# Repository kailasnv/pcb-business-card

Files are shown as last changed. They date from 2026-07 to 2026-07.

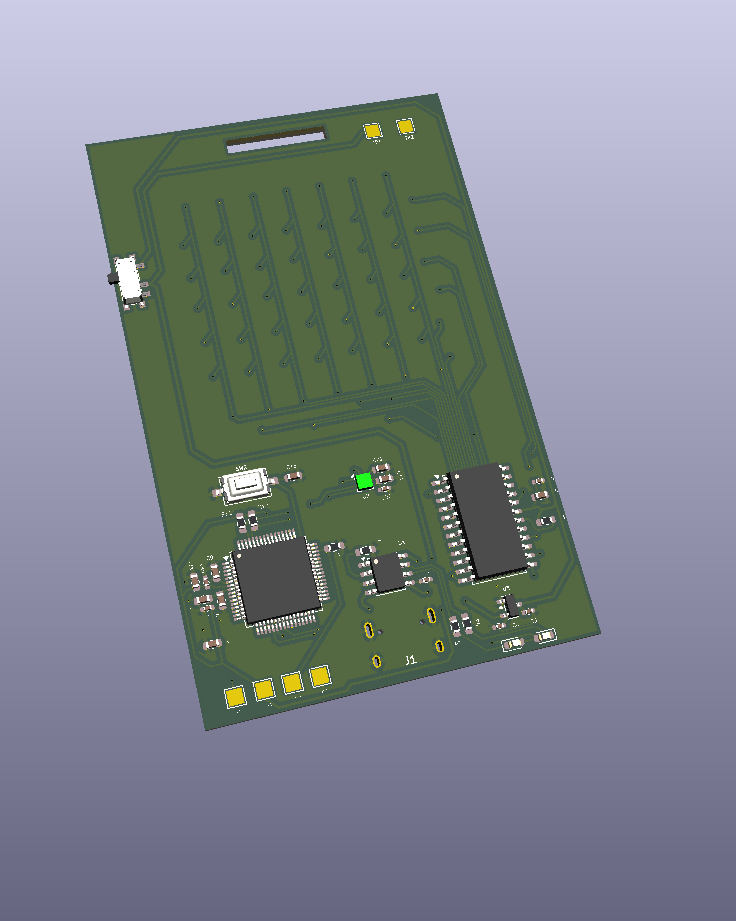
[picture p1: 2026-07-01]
docs/images/contact_card_v1.png

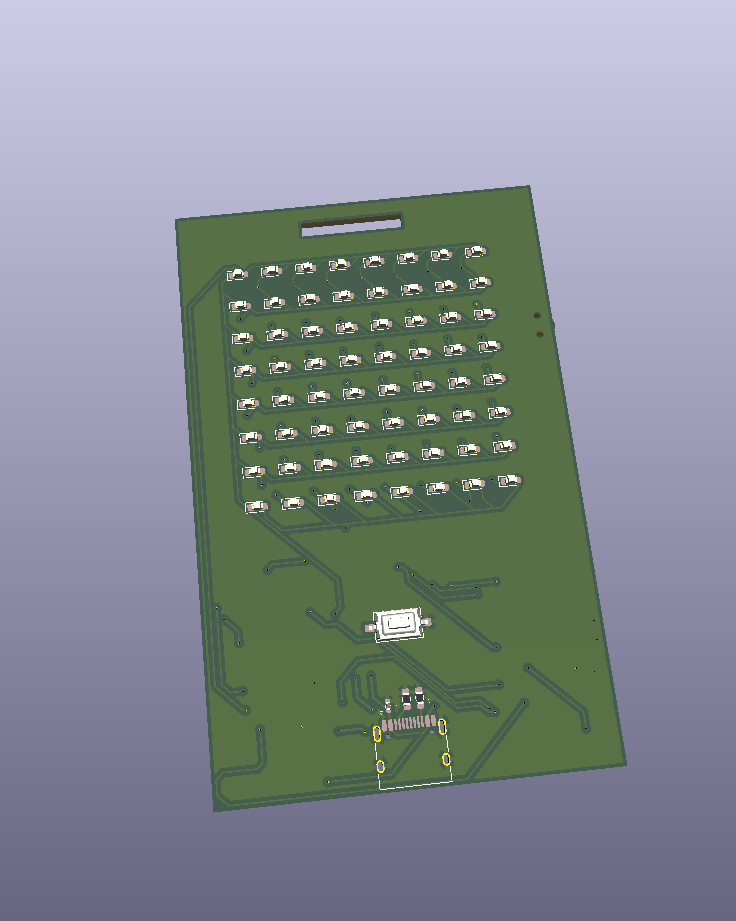
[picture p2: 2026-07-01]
docs/images/contact_card_v1_frontside.png

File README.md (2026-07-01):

# PCB Business Card

A creditcard sized custom PCB that doubles as a contact card and an interactive embedded demo. Designed from scratch, No dev board, no modules, bare chip bring up on a custom 2 layer board.

---

## What it does

| Mode | Trigger | Description |
|---|---|---|
| **Scroll** | Idle | Scrolls name and contact details across the 8×8 LED matrix |
| **Flappy Bird** | Button press | Classic Flappy Bird on an 8×8 grid |
| **Ball** | Tilt card | 1-pixel ball rolls around the matrix responding to physical tilt |

---

## Hardware

| Component | Part | Purpose |
|---|---|---|
| MCU | STM32G071RBT6 (LQFP-64) | Main processor, Cortex-M0+ @ 64MHz |
| LED Driver | MAX7219 (SOIC-24) | Drives 8×8 LED matrix over SPI |
| Display | 8×8 red LED matrix (0603 LEDs) | Output display |
| Accelerometer | IIS2DLPC (LGA-12) | 3-axis tilt sensing over I²C |
| Charger | TP4056 (SOP-8) | LiPo charging via USB-C |
| Regulator | MCP1700 | 3.3V LDO from LiPo |
| Power | 3.7V 1500mAh LiPo | Battery |
| Input | SMD tactile switch (3×6mm) | Game button |
| Connector | USB-C (16-pin SMD) | Charging input |

---

## Schematic overview

Five sub-circuits:
- **Power** — USB-C → TP4056 → LiPo → MCP1700 → 3.3V rail
- **MCU** — STM32G071RB with decoupling, BOOT0 pull-down, SWD pads
- **LED matrix** — MAX7219 driven over SPI, 64× 0603 LEDs in 8×8 grid
- **Accelerometer** — IIS2DLPC over I²C with additional INT1 interrupt line to MCU
- **Input** — Tactile button + 4-pad SWD debug port

---

###### Firmware (in progress)

---

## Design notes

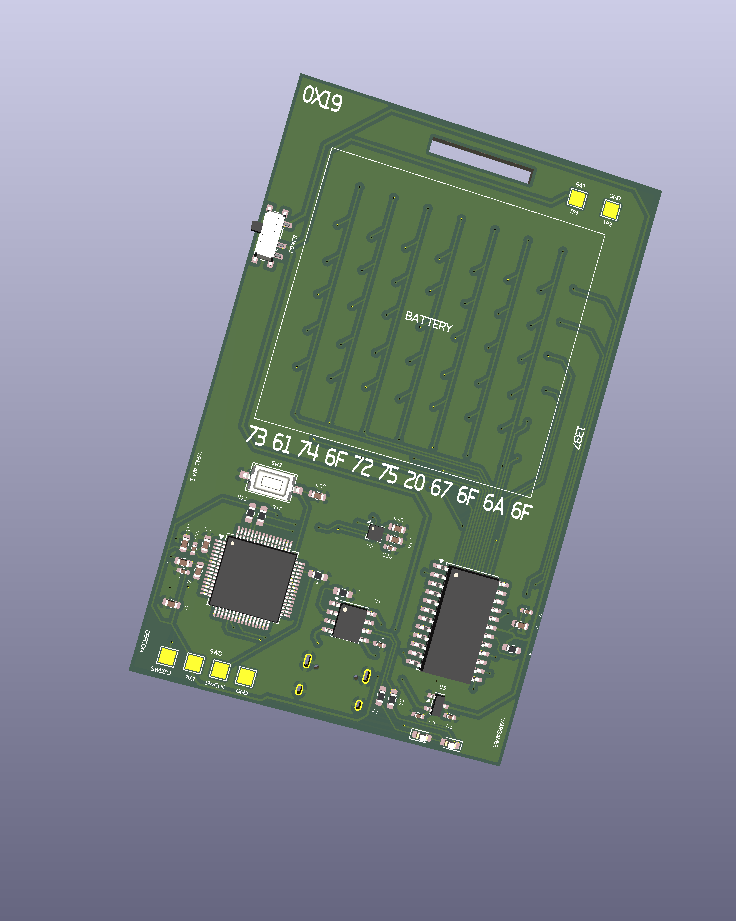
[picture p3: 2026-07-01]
docs/images/contact_card_v1_IMG3.png

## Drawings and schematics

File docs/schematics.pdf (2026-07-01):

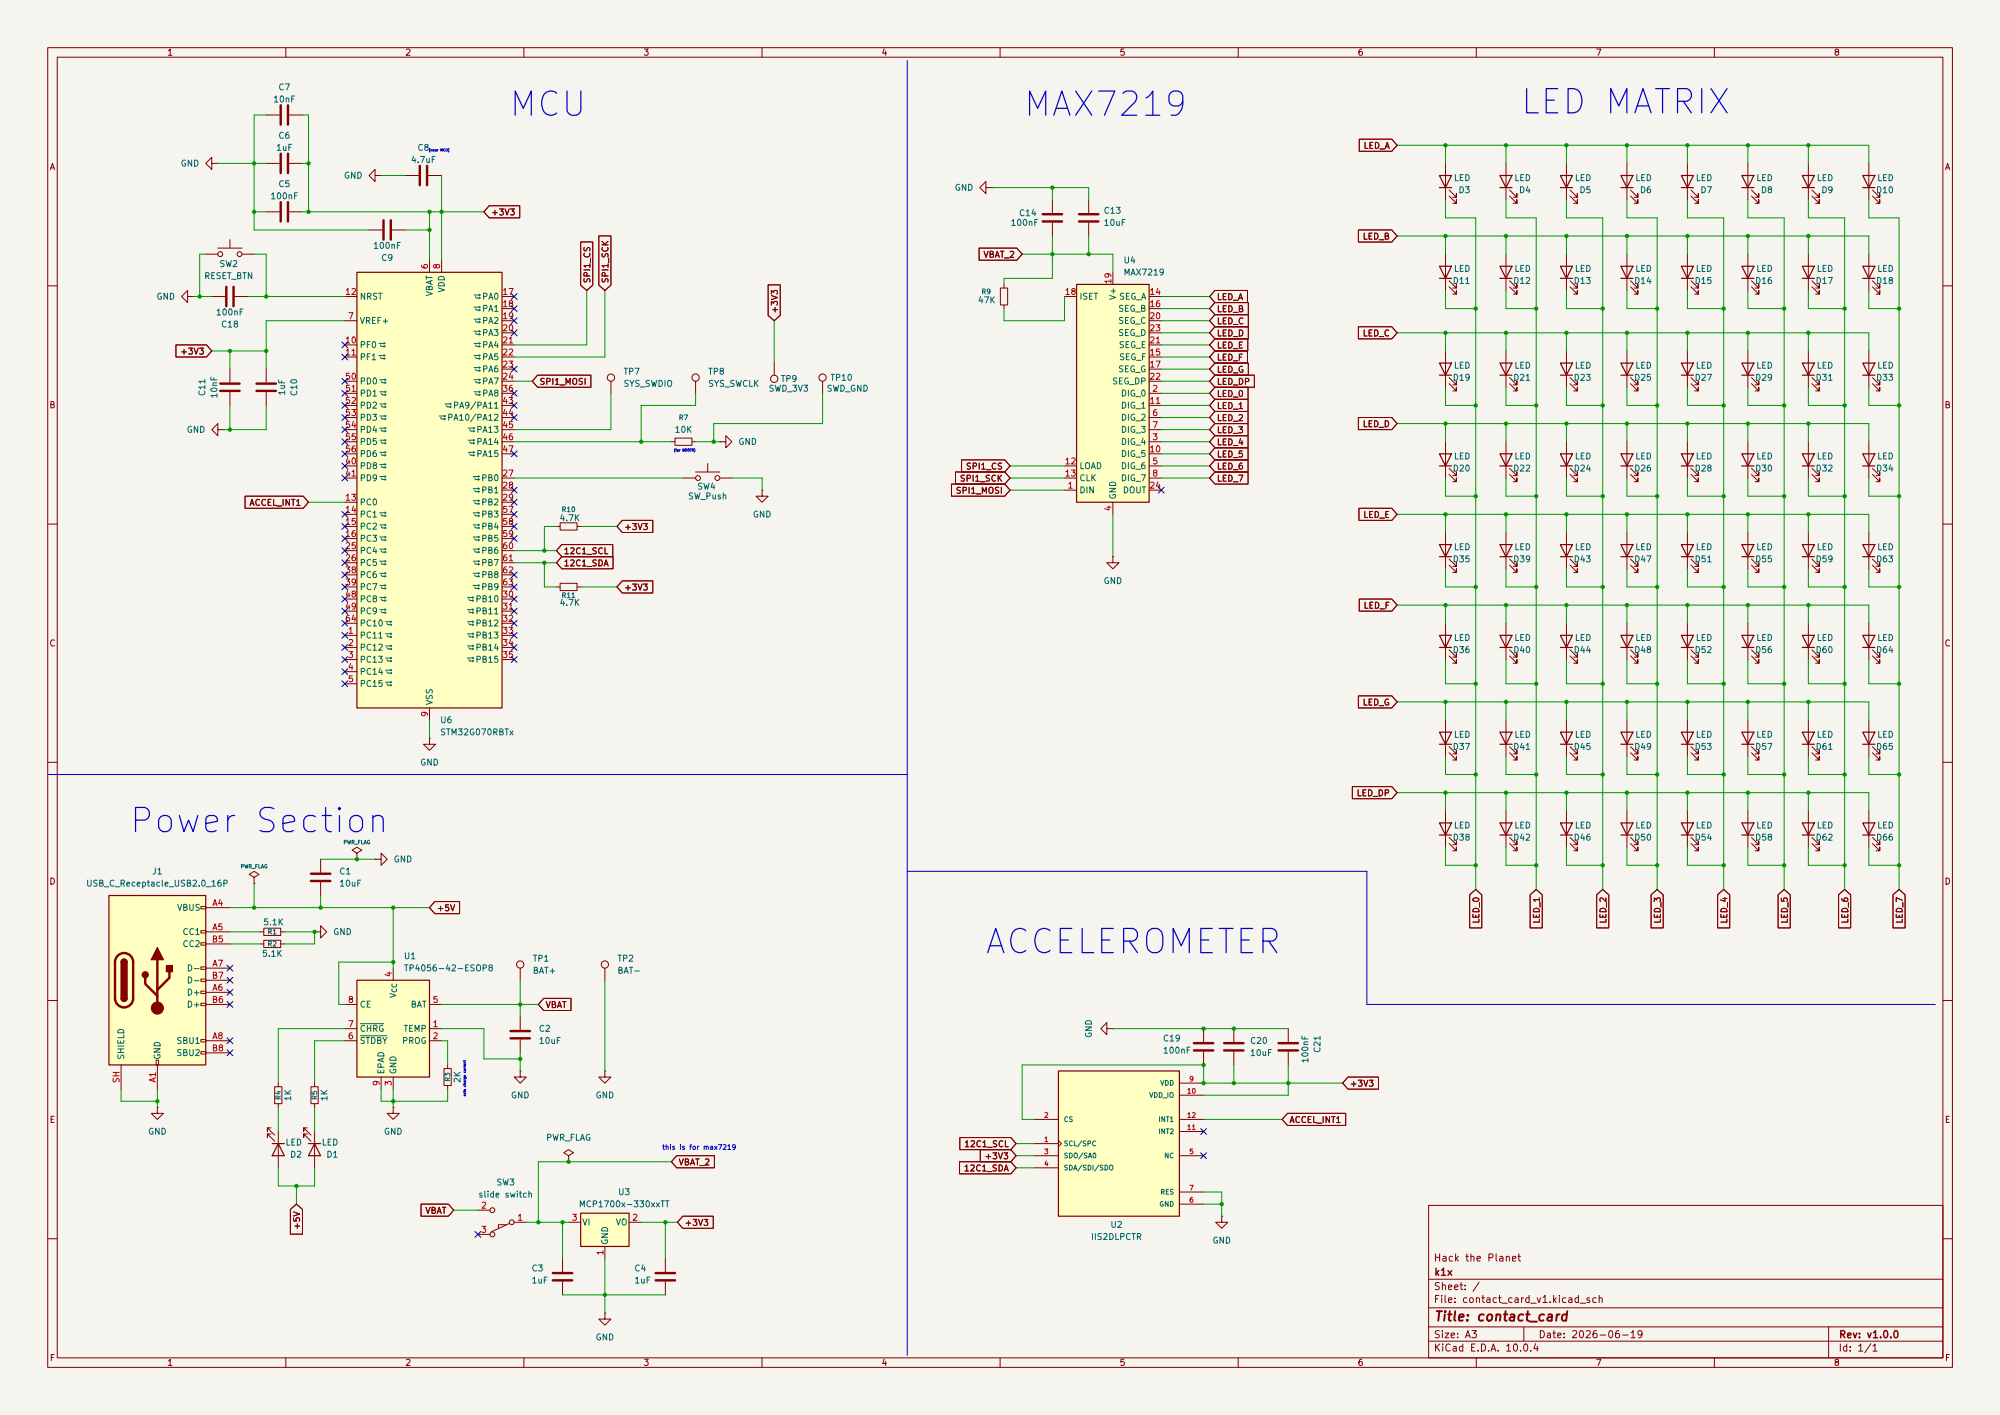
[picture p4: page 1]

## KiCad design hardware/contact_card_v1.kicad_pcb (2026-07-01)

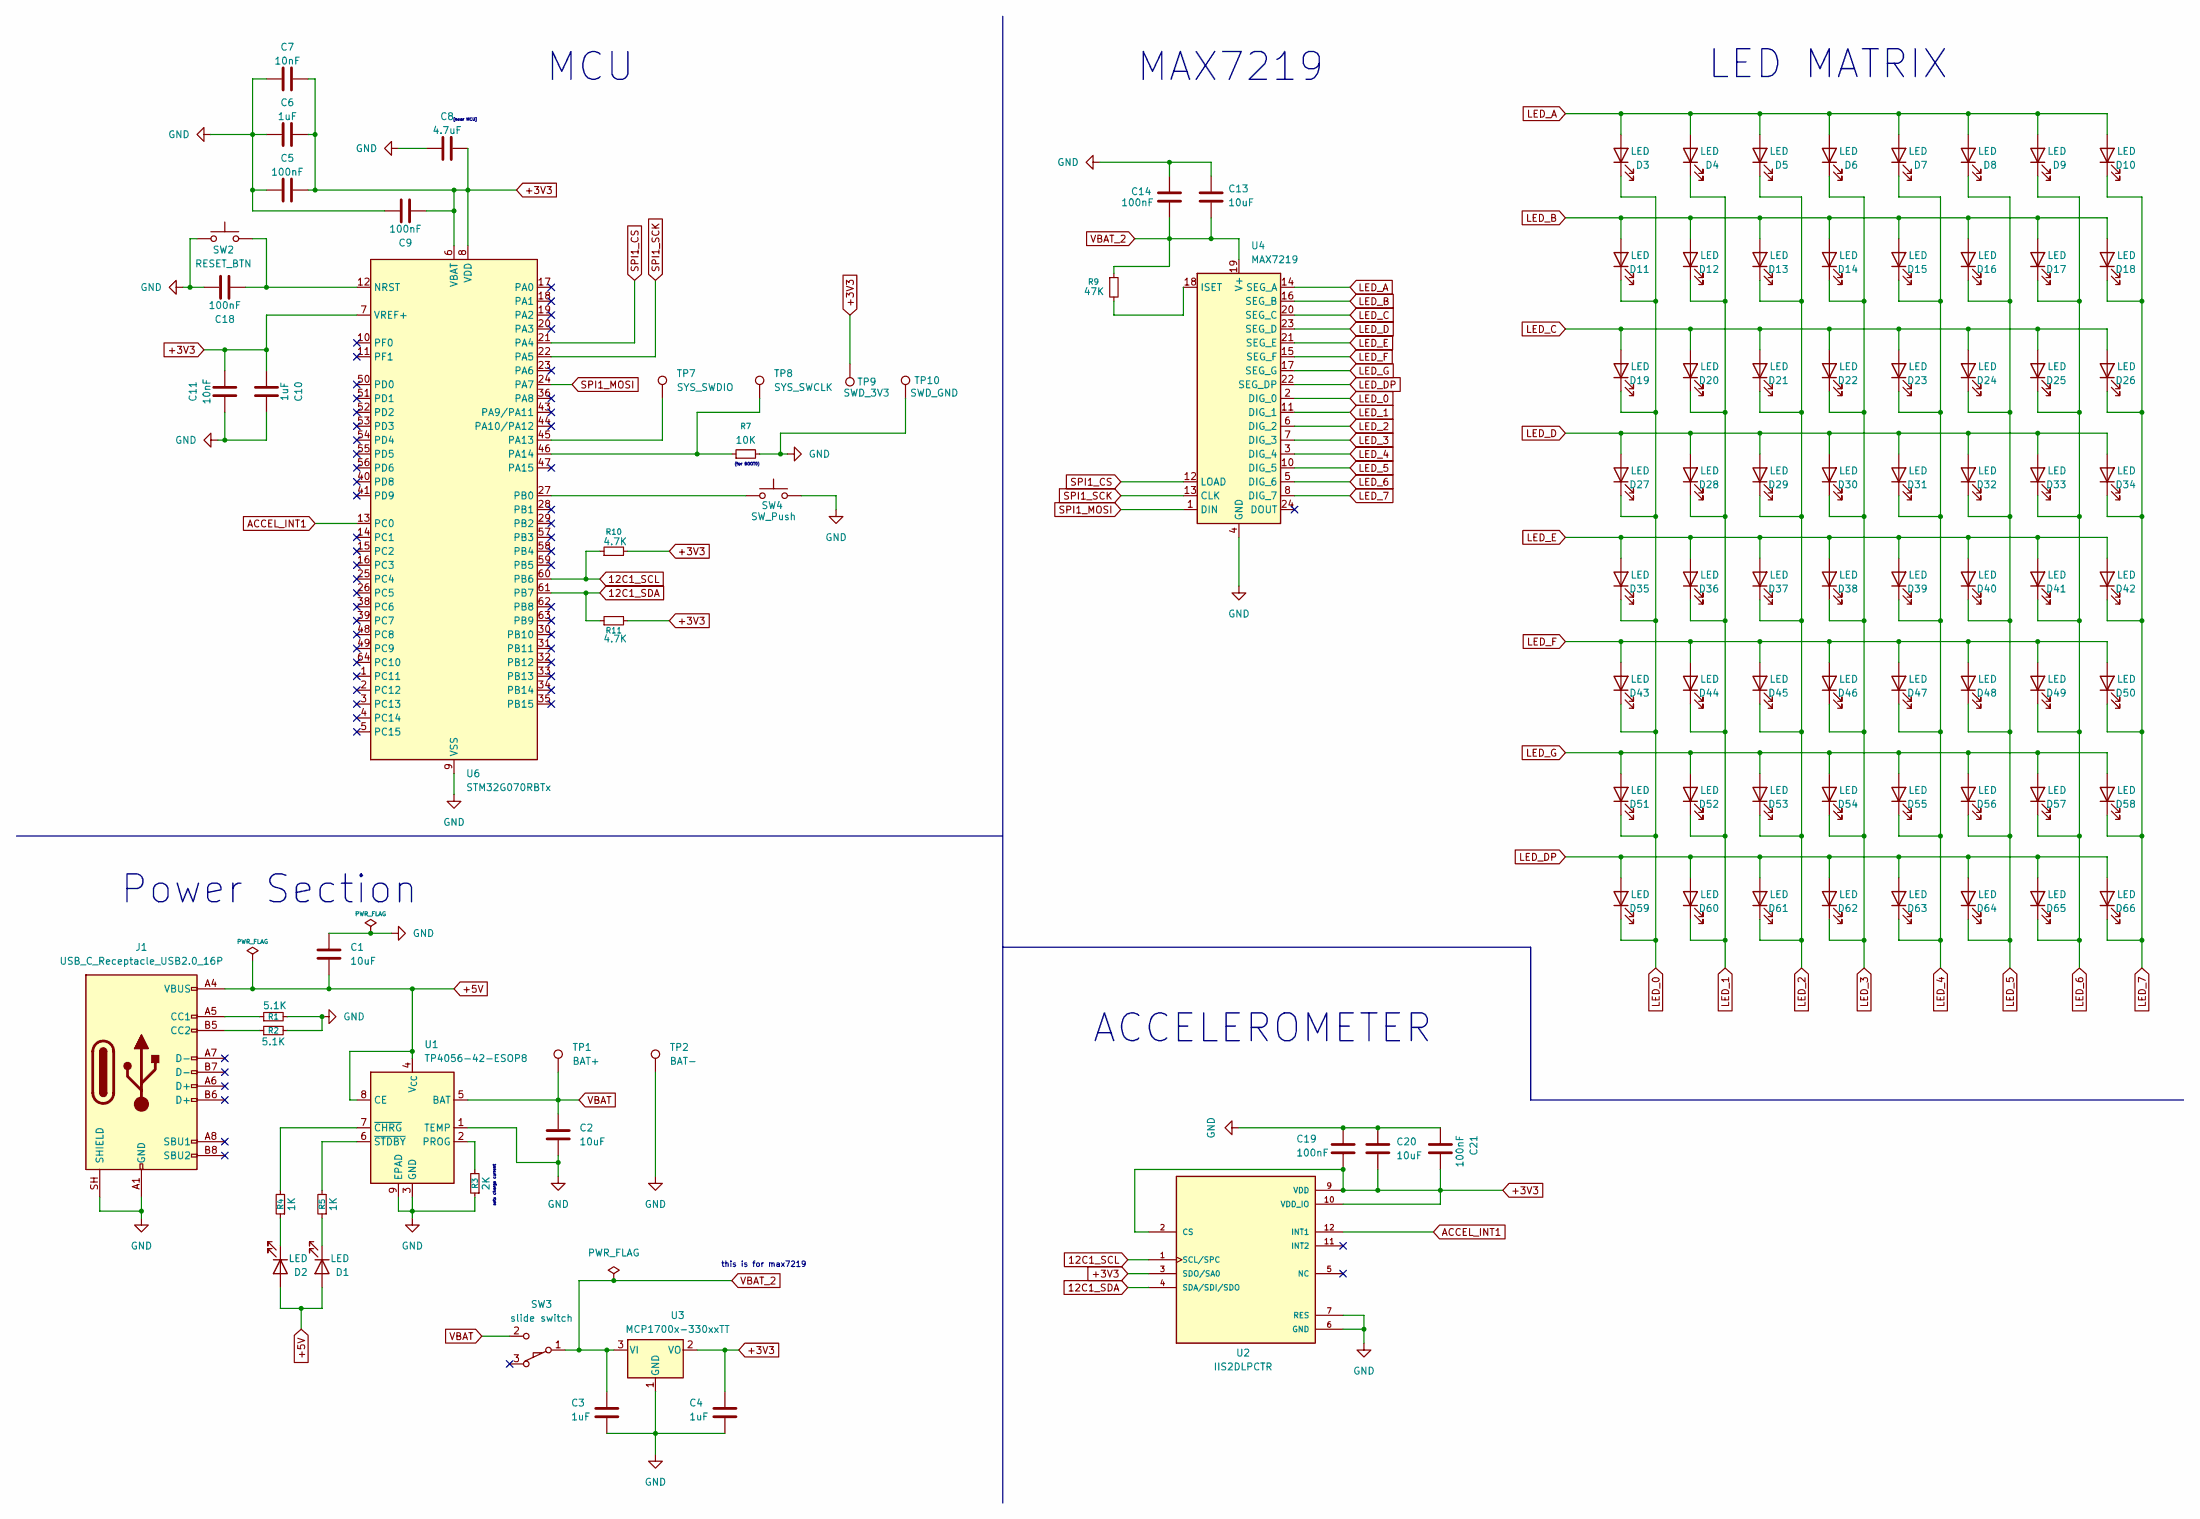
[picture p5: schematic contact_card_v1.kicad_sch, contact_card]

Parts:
C1, C2, C13, C20: 10uF; C_0402_1005Metric_Pad0.74x0.62mm_HandSolder
C3, C4, C6, C10: 1uF; C_0402_1005Metric_Pad0.74x0.62mm_HandSolder
C5, C9, C14, C18, C19, C21: 100nF; C_0603_1608Metric
C7, C11: 10nF; C_0603_1608Metric
C8: 4.7uF; C_0603_1608Metric
D1, D2, D3, D4, D5, D6, D7, D8, D9, D10, D11, D12, D13, D14, D15, D16, D17, D18, D19, D20, D21, D22, D23, D24, D25, D26, D27, D28, D29, D30, D31, D32, D33, D34, D35, D36, D37, D38, D39, D40, D41, D42, D43, D44, D45, D46, D47, D48, D49, D50, D51, D52, D53, D54, D55, D56, D57, D58, D59, D60, D61, D62, D63, D64, D65, D66: LED; LED_0603_1608Metric_Pad1.05x0.95mm_HandSolder
J1: USB_C_Receptacle_USB2.0_16P; USB_C_Receptacle_HRO_TYPE-C-31-M-12
R1, R2: 5.1K; R_0603_1608Metric_Pad0.98x0.95mm_HandSolder
R3: 2K; R_0603_1608Metric_Pad0.98x0.95mm_HandSolder
R4, R5: 1K; R_0603_1608Metric_Pad0.98x0.95mm_HandSolder
R7: 10K; R_0603_1608Metric_Pad0.98x0.95mm_HandSolder
R9: 47K; R_0603_1608Metric_Pad0.98x0.95mm_HandSolder
R10, R11: 4.7K; R_0603_1608Metric_Pad0.98x0.95mm_HandSolder
SW2: RESET_BTN; SW_Tactile_SPST_NO_Straight_CK_PTS636Sx25SMTRLFS
SW3: slide switch; SW_SPDT_PCM12
SW4: SW_Push; SW_Tactile_SPST_NO_Straight_CK_PTS636Sx25SMTRLFS
TP1: BAT+; TestPoint_Pad_2.0x2.0mm
TP2: BAT-; TestPoint_Pad_2.0x2.0mm
TP7: SYS_SWDIO; TestPoint_Pad_2.0x2.0mm
TP8: SYS_SWCLK; TestPoint_Pad_2.0x2.0mm
TP9: SWD_3V3; TestPoint_Pad_2.0x2.0mm
TP10: SWD_GND; TestPoint_Pad_2.0x2.0mm
U1: TP4056-42-ESOP8; SOIC-8-1EP_3.9x4.9mm_P1.27mm_EP2.29x3mm
U2: IIS2DLPCTR; LGA-12_2x2mm_P0.5mm; PARTREV 4
U3: MCP1700x-330xxTT; SOT-23
U4: MAX7219; SOIC-24W_7.5x15.4mm_P1.27mm
U6: STM32G070RBTx; LQFP-64_10x10mm_P0.5mm

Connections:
12C1_SCL: R10.1, U2.1 (SCL/SPC), U6.60 (PB6)
12C1_SDA: R11.1, U2.4 (SDA/SDI/SDO), U6.61 (PB7)
+3V3: C4.1, C5.2, C6.2, C7.2, C8.2, C9.1, C10.2, C11.1, C19.2, C20.2, C21.1, R10.2, R11.2, TP9.1 (1_1), U2.2 (CS), U2.3 (SDO/SA0), U2.9 (VDD), U2.10 (VDD_IO), U3.2 (VO), U6.6 (VBAT), U6.7 (VREF+), U6.8 (VDD)
+5V: C1.2, D1.2 (A), D2.2 (A), J1.A4 (VBUS), J1.A9 (VBUS), J1.B4 (VBUS), J1.B9 (VBUS), U1.4 (V_{CC}), U1.8 (CE)
ACCEL_INT1: U2.12 (INT1), U6.13 (PC0)
GND: C1.1, C2.2, C3.2, C4.2, C5.1, C6.1, C7.1, C8.1, C9.2, C10.1, C11.2, C13.1, C14.1, C18.2, C19.1, C20.1, C21.2, J1.A1 (GND), J1.A12 (GND), J1.B1 (GND), J1.B12 (GND), J1.SH (SHIELD), R1.2, R2.2, R3.1, R7.2, SW2.1, SW4.2, TP2.1 (1_1), TP10.1 (1_1), U1.1 (TEMP), U1.3 (GND), U1.9 (EPAD), U2.6 (GND), U2.7 (RES), U2.8 (GND), U3.1 (GND), U4.4 (GND), U4.9 (GND), U6.9 (VSS)
LED_0: D3.1 (K), D11.1 (K), D19.1 (K), D27.1 (K), D35.1 (K), D43.1 (K), D51.1 (K), D59.1 (K), U4.2 (DIG_0)
LED_1: D4.1 (K), D12.1 (K), D20.1 (K), D28.1 (K), D36.1 (K), D44.1 (K), D52.1 (K), D60.1 (K), U4.11 (DIG_1)
LED_2: D5.1 (K), D13.1 (K), D21.1 (K), D29.1 (K), D37.1 (K), D45.1 (K), D53.1 (K), D61.1 (K), U4.6 (DIG_2)
LED_3: D6.1 (K), D14.1 (K), D22.1 (K), D30.1 (K), D38.1 (K), D46.1 (K), D54.1 (K), D62.1 (K), U4.7 (DIG_3)
LED_4: D7.1 (K), D15.1 (K), D23.1 (K), D31.1 (K), D39.1 (K), D47.1 (K), D55.1 (K), D63.1 (K), U4.3 (DIG_4)
LED_5: D8.1 (K), D16.1 (K), D24.1 (K), D32.1 (K), D40.1 (K), D48.1 (K), D56.1 (K), D64.1 (K), U4.10 (DIG_5)
LED_6: D9.1 (K), D17.1 (K), D25.1 (K), D33.1 (K), D41.1 (K), D49.1 (K), D57.1 (K), D65.1 (K), U4.5 (DIG_6)
LED_7: D10.1 (K), D18.1 (K), D26.1 (K), D34.1 (K), D42.1 (K), D50.1 (K), D58.1 (K), D66.1 (K), U4.8 (DIG_7)
LED_A: D3.2 (A), D4.2 (A), D5.2 (A), D6.2 (A), D7.2 (A), D8.2 (A), D9.2 (A), D10.2 (A), U4.14 (SEG_A)
LED_B: D11.2 (A), D12.2 (A), D13.2 (A), D14.2 (A), D15.2 (A), D16.2 (A), D17.2 (A), D18.2 (A), U4.16 (SEG_B)
LED_C: D19.2 (A), D20.2 (A), D21.2 (A), D22.2 (A), D23.2 (A), D24.2 (A), D25.2 (A), D26.2 (A), U4.20 (SEG_C)
LED_D: D27.2 (A), D28.2 (A), D29.2 (A), D30.2 (A), D31.2 (A), D32.2 (A), D33.2 (A), D34.2 (A), U4.23 (SEG_D)
LED_DP: D59.2 (A), D60.2 (A), D61.2 (A), D62.2 (A), D63.2 (A), D64.2 (A), D65.2 (A), D66.2 (A), U4.22 (SEG_DP)
LED_E: D35.2 (A), D36.2 (A), D37.2 (A), D38.2 (A), D39.2 (A), D40.2 (A), D41.2 (A), D42.2 (A), U4.21 (SEG_E)
LED_F: D43.2 (A), D44.2 (A), D45.2 (A), D46.2 (A), D47.2 (A), D48.2 (A), D49.2 (A), D50.2 (A), U4.15 (SEG_F)
LED_G: D51.2 (A), D52.2 (A), D53.2 (A), D54.2 (A), D55.2 (A), D56.2 (A), D57.2 (A), D58.2 (A), U4.17 (SEG_G)
unnamed: D1.1 (K), R5.1
unnamed: D2.1 (K), R4.1
unnamed: J1.A5 (CC1), R1.1
unnamed: J1.B5 (CC2), R2.1
unnamed: R3.2, U1.2 (PROG)
unnamed: R4.2, U1.7 (~CHRG)
unnamed: R5.2, U1.6 (~STDBY)
unnamed: R9.2, U4.18 (ISET)
unnamed: C18.1, SW2.2, U6.12 (NRST)
unnamed: TP7.1 (1_1), U6.45 (PA13)
unnamed: R7.1, TP8.1 (1_1), U6.46 (PA14)
unnamed: SW4.1, U6.27 (PB0)
SPI1_CS: U4.12 (LOAD), U6.21 (PA4)
SPI1_MOSI: U4.1 (DIN), U6.24 (PA7)
SPI1_SCK: U4.13 (CLK), U6.22 (PA5)
VBAT: C2.1, SW3.2 (B), TP1.1 (1_1), U1.5 (BAT)
VBAT_2: C3.1, C13.2, C14.2, R9.1, SW3.1 (A), U3.3 (VI), U4.19 (V+)

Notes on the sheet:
[near MCU]
sets charge current
LED MATRIX
MCU
MAX7219
Power Section
this is for max7219
(for BOOT0)
ACCELEROMETER

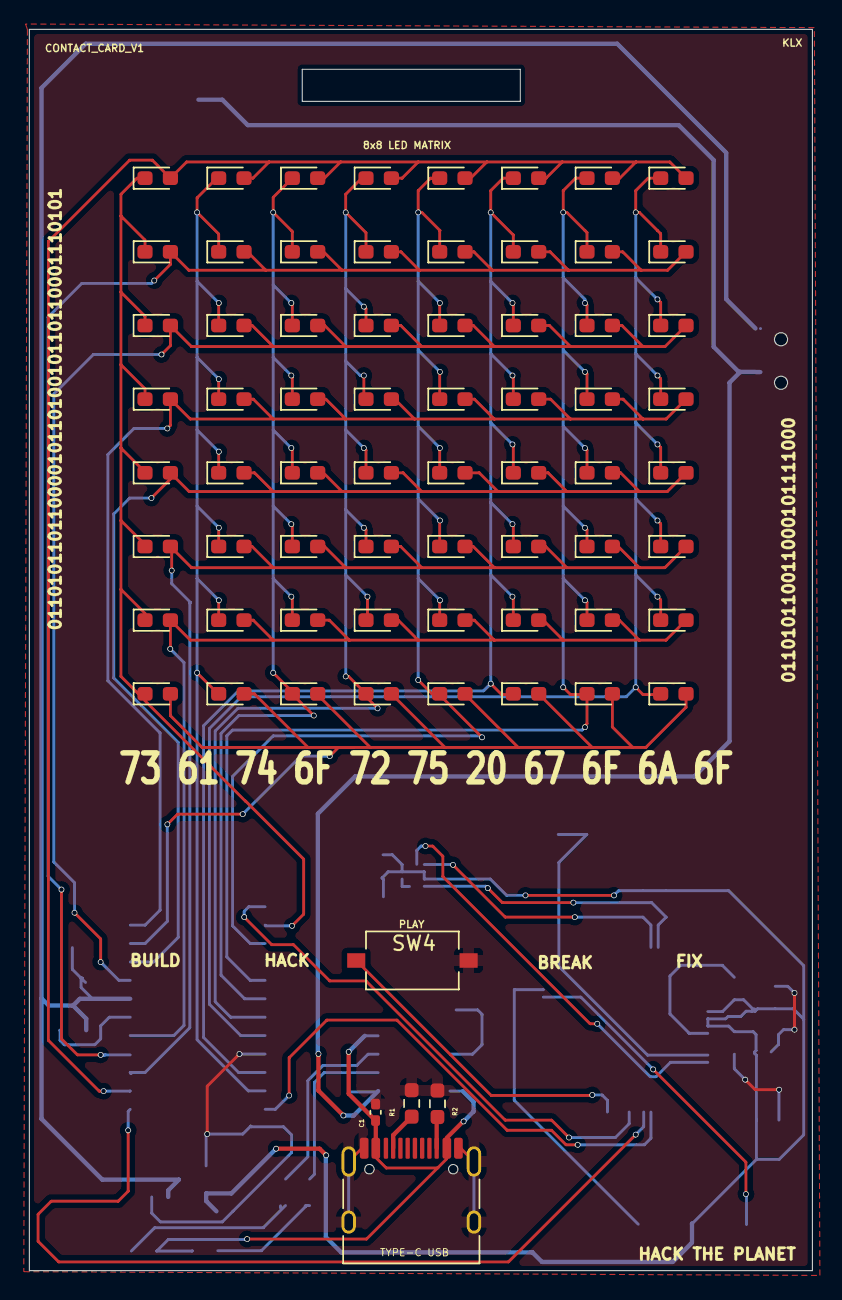
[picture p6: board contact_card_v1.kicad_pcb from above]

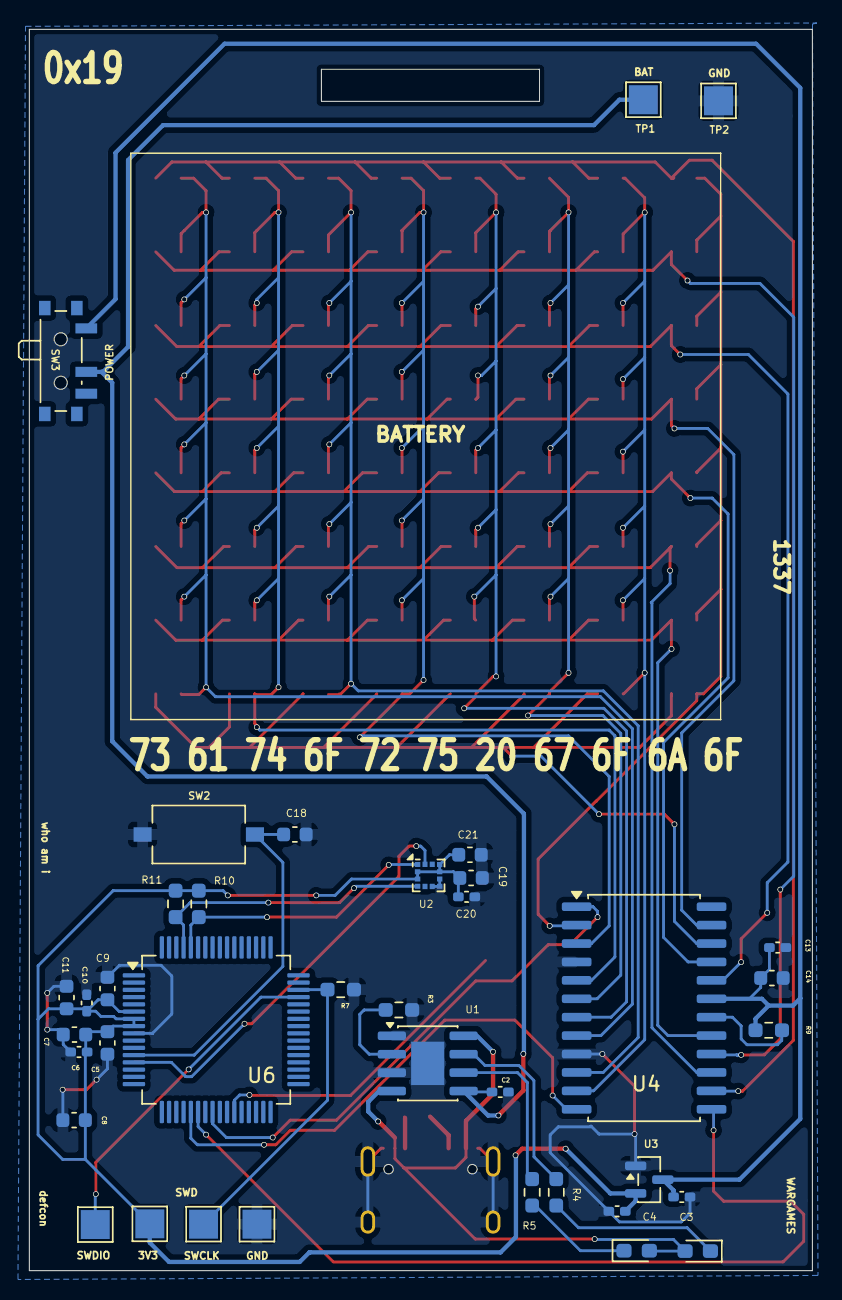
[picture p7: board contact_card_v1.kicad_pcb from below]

Board: 2 copper layers, 54.0 x 85.6 mm, 107 parts (38 on the bottom side), 39 nets.

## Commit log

2026-07-01 pcb design done
    [contact_card_v1-B_Cu.gbr, contact_card_v1-B_Mask.gbr, contact_card_v1-B_Paste.gbr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]
2026-07-01 restructure: organize into hardware/firmware/docs layout, remove generated files
    [contact_card_v1-B_Cu.gbr, contact_card_v1-B_Mask.gbr, contact_card_v1-B_Paste.gbr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]
